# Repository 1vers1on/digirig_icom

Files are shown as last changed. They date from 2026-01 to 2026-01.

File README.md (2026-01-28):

# ICOM IC-2730 Digital Controller

A custom hardware controller for the ICOM IC-2730 radio, featuring digital audio processing and USB connectivity.

## Overview

This project provides a digital interface for the ICOM IC-2730 radio using a Raspberry Pi RP2350 microcontroller and TLV320AIC3204 audio codec. It handles both transmit and receive audio digitally while managing the radio's unique logic level requirements.

## Hardware
### Main Components

- **Microcontroller: Raspberry Pi RP2350**
  - High processing power
  - Native USB support
  - Familiar development ecosystem

- **Audio Codec: TLV320AIC3204**
  - Integrated DAC and ADC
  - High-quality audio processing

## Key Features
  - USB connectivity for computer interface
  - Bidirectional audio processing (TX/RX)
  - Analog switching circuitry
  - LDO power regulation
  - 3D-printed enclosure with screw mounting

## Design Challenges
**Logic Level Weirdness**
The ICOM IC-2730 uses some very unusual logic levels that I've never encountered before:

- High: 5V
- Low: 3.1V (yes, really!)

**Solution**

- RX path: LM393 comparator to handle the odd voltage levels
- TX path: 5V level shifter (if it reads 3.1V as low, it should read 0V as low too)

**Power Management**
Originally considered a buck converter for efficiency, but went with an LDO since it's perfectly adequate for this application and simpler to implement.

## Notes

- This was my first time using Fusion 360 for CAD work
- Spent way too long figuring out MOSFET power switching
- Enclosure uses screws instead of glue for user serviceability

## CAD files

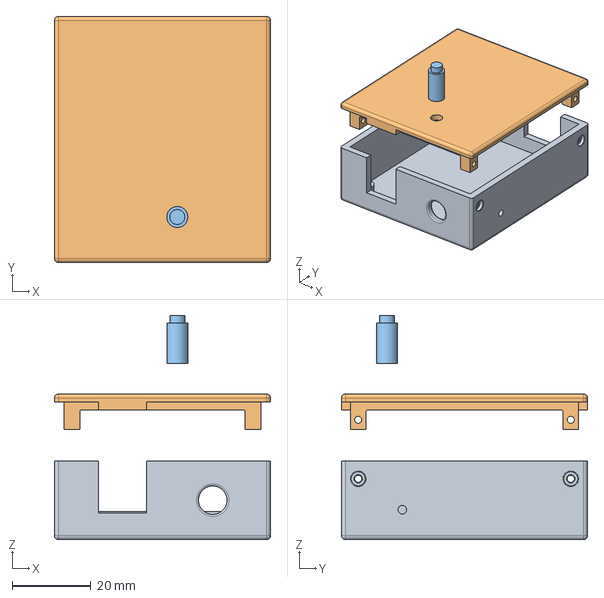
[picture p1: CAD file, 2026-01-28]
icom_digirig_case.step
54.9 x 62.5 x 57.0 mm

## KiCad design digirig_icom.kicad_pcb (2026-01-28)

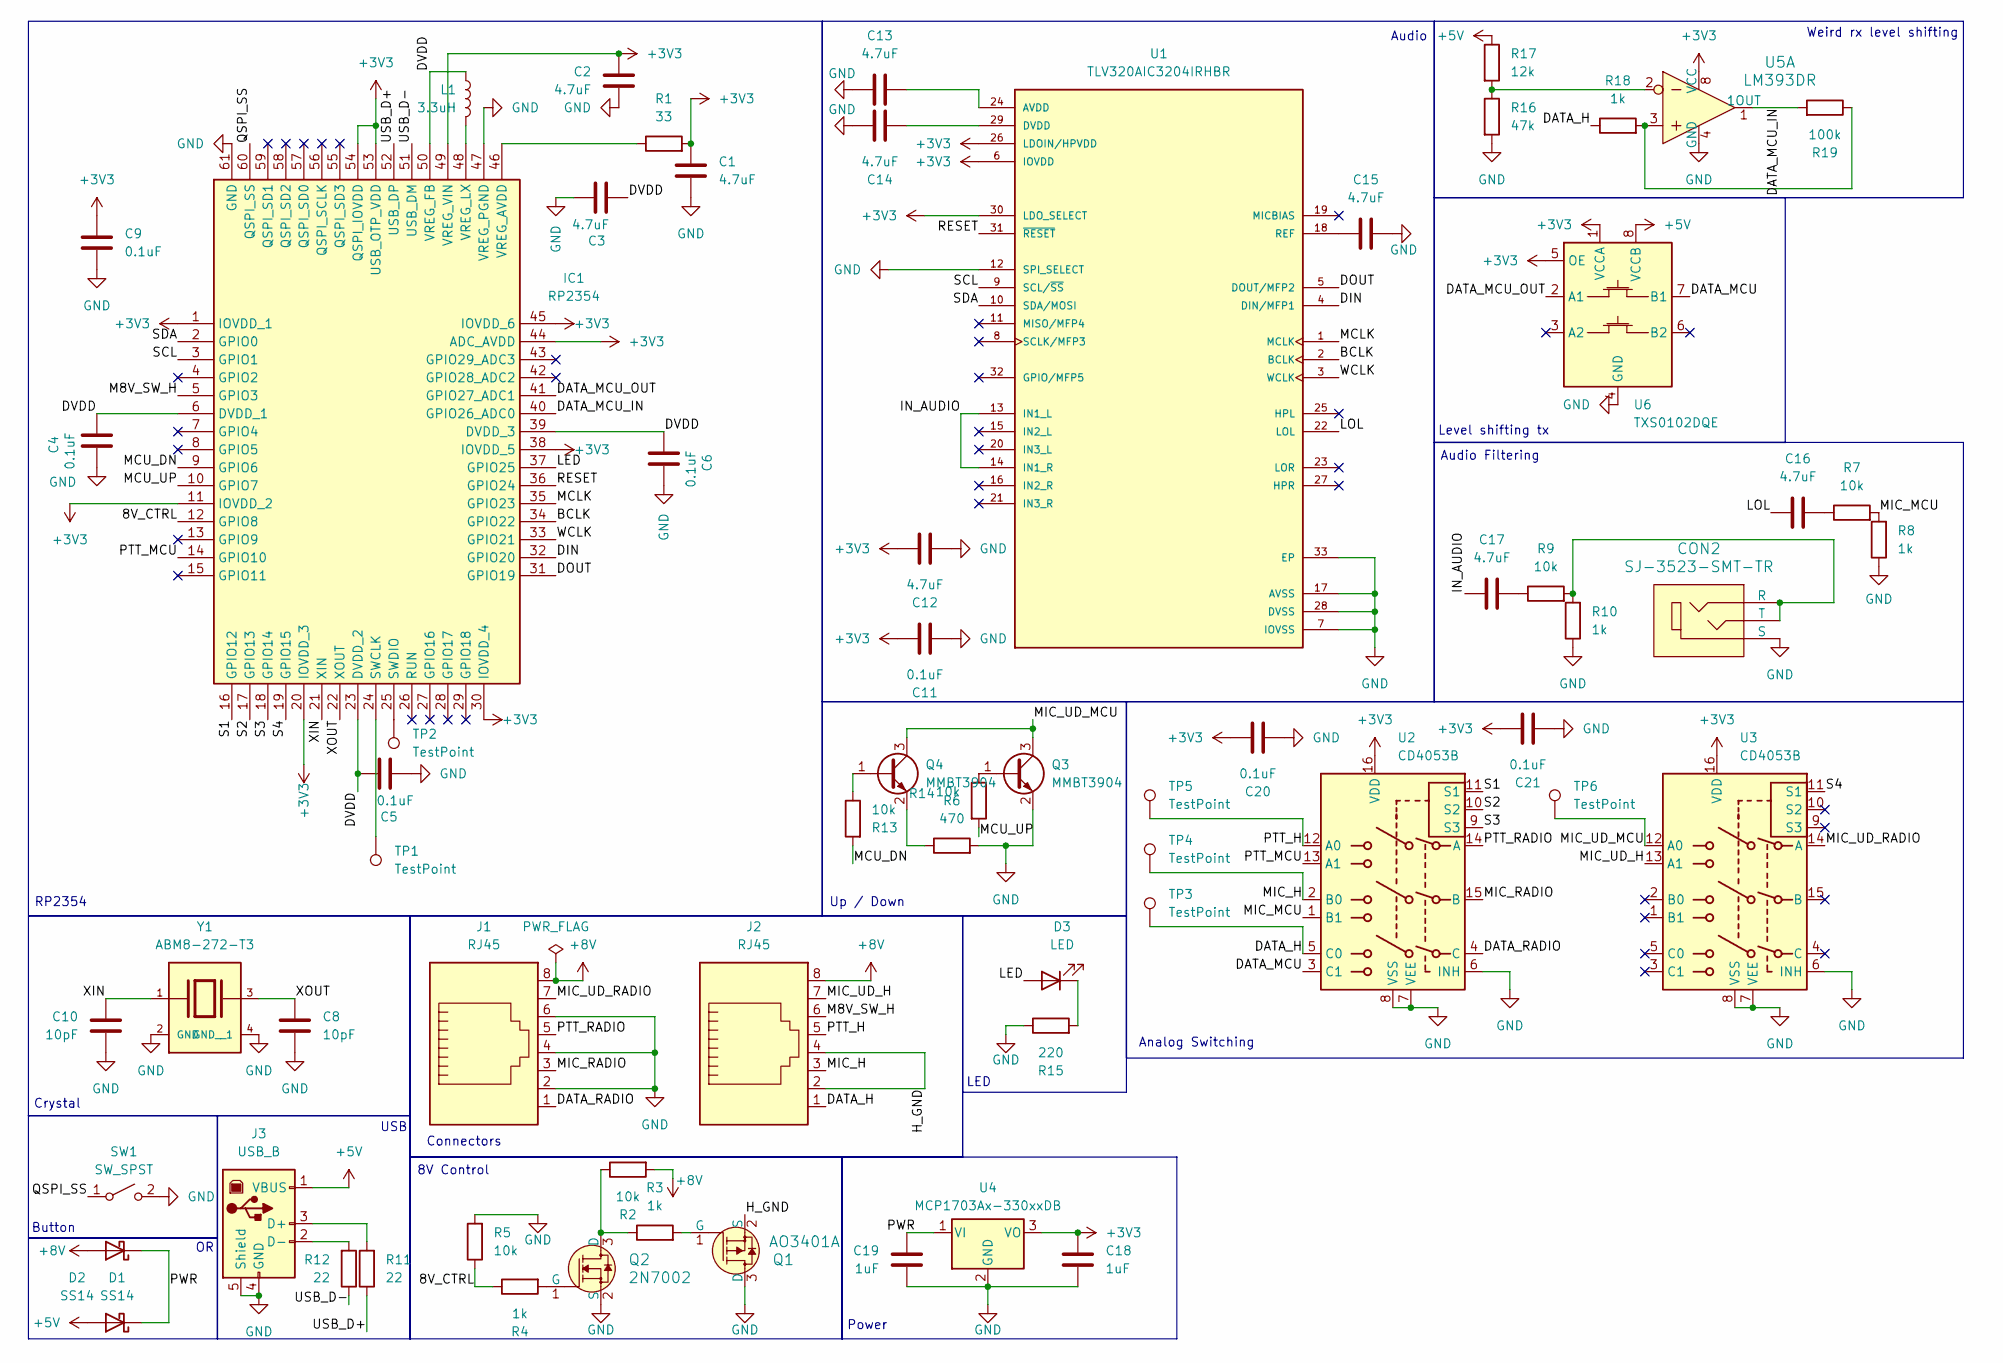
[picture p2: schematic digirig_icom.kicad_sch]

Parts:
C1, C2, C3, C12, C13, C14, C15, C16, C17: 4.7uF; C_0402_1005Metric; Digi-Key_PN 1276-1482-2-ND
C4, C5, C6, C9, C11, C20, C21: 0.1uF; C_0402_1005Metric; Digi-Key_PN 1276-1043-2-ND
C8, C10: 10pF; C_0402_1005Metric; Digi-Key_PN 490-6186-2-ND
C18, C19: 1uF; C_0402_1005Metric; Digi-Key_PN 1276-1010-2-ND
CON2: SJ-3523-SMT-TR; Switch_Slide_11.6x4mm_SJ-3523-SMT; MPN SJ-3523-SMT-TR; Digi-Key_PN CP-3523SJCT-ND
D1, D2: SS14; D_SMA; Digi-Key_PN SS14TR-ND
D3: LED; LED_0603_1608Metric; Digi-Key_PN 475-LSQ976-NR-1TR-ND
IC1: RP2354; QFN40P700X700X90-61N-D; Manufacturer_Part_Number RP2350A-CT; Digi-Key_PN 2648-SC1511(13)-A4TR-ND
J1, J2: RJ45; RJ45_Amphenol_54602-x08_Horizontal; Digi-Key_PN 609-1046-ND
J3: USB_B; USB_B_Lumberg_2411_02_Horizontal; Digi-Key_PN 5405-241106-ND
L1: 3.3uH; AOTAB201610S3R3101T; Digi-Key_PN 535-AOTA-B201610S3R3-101-TTR-ND
Q1: AO3401A; SOT-23-3; MPN AO3401A; Digi-Key_PN 785-1001-1-ND
Q2: 2N7002; SOT-23-3; MPN 2N7002; Digi-Key_PN 2N7002NCT-ND
Q3, Q4: MMBT3904; SOT-23; Digi-Key_PN 4878-MMBT3904TR-ND
R1: 33; R_0402_1005Metric; Digi-Key_PN 311-33JRTR-ND
R2, R5, R7, R9, R13, R14: 10k; R_0402_1005Metric; Digi-Key_PN 311-10.0KLRTR-ND
R3, R4, R8, R10, R18: 1k; R_0402_1005Metric; Digi-Key_PN 311-1.0KJRTR-ND
R6: 470; R_0402_1005Metric; Digi-Key_PN 311-470LRTR-ND
R11, R12: 22; R_0402_1005Metric; Digi-Key_PN 311-22.0LRTR-ND
R15: 220; R_0603_1608Metric; Digi-Key_PN 311-220HRTR-ND
R16: 47k; R_0402_1005Metric; Digi-Key_PN 311-47.0KLRTR-ND
R17: 12k; R_0402_1005Metric; Digi-Key_PN P12KDCTR-ND
R19: 100k; R_0402_1005Metric; Digi-Key_PN 311-100KJRTR-ND
SW1: SW_SPST; SW_SPST_CK_RS282G05A3; Digi-Key_PN CKN10384TR-ND
TP1, TP2, TP3, TP4, TP5, TP6: TestPoint; TestPoint_Pad_D1.0mm
U1: TLV320AIC3204IRHBR; QFN50P500X500X100-33N; PARTREV E; Digi-Key_PN 296-23775-2-ND
U2, U3: CD4053B; TSSOP-16_4.4x5mm_P0.65mm; Digi-Key_PN 296-14117-2-ND
U4: MCP1703Ax-330xxDB; SOT-223-3_TabPin2; Digi-Key_PN MCP1703A-3302E/DB-ND
U5: LM393DR; SOIC-8_W3.9mm; MPN LM393DR; Digi-Key_PN 296-1015-1-ND
U6: TXS0102DQE; X2SON-8_1.4x1mm_P0.35mm; Digi-Key_PN 296-28368-2-ND
Y1: ABM8-272-T3; XTAL_ABM8-272-T3; PARTREV 07-29-20; Digi-Key_PN 535-ABM8-272-T3TR-ND

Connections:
+3V3: C1.1, C2.2, C9.2, C11.1, C12.1, C18.1, C20.1, C21.1, IC1.1 (IOVDD_1), IC1.11 (IOVDD_2), IC1.20 (IOVDD_3), IC1.30 (IOVDD_4), IC1.38 (IOVDD_5), IC1.44 (ADC_AVDD), IC1.45 (IOVDD_6), IC1.49 (VREG_VIN), IC1.53 (USB_OTP_VDD), IC1.54 (QSPI_IOVDD), R1.2, U1.6 (IOVDD), U1.26 (LDOIN/HPVDD), U1.30 (LDO_SELECT), U2.16 (VDD), U3.16 (VDD), U4.3 (VO), U5.8 (VCC), U6.1 (VCCA), U6.5 (OE)
+5V: D1.2 (A), J3.1 (VBUS), R17.1, U6.8 (VCCB)
+8V: D2.2 (A), J1.8, J2.8, R2.2
/8V_CTRL: IC1.12 (GPIO8), R4.1, R5.1
/BCLK: IC1.34 (GPIO22), U1.2 (BCLK)
/DATA_H: J2.1, R18.1, TP3.1, U2.5 (C0)
/DATA_MCU: U2.3 (C1), U6.7 (B1)
/DATA_MCU_IN: IC1.40 (GPIO26_ADC0), R19.2, U5.1 (1OUT)
/DATA_MCU_OUT: IC1.41 (GPIO27_ADC1), U6.2 (A1)
/DATA_RADIO: J1.1, U2.4 (C)
/DIN: IC1.32 (GPIO20), U1.4 (DIN/MFP1)
/DOUT: IC1.31 (GPIO19), U1.5 (DOUT/MFP2)
/DVDD: C3.1, C4.1, C5.1, C6.1, IC1.6 (DVDD_1), IC1.23 (DVDD_2), IC1.39 (DVDD_3), IC1.50 (VREG_FB), L1.2
/H_GND: J2.2, J2.4, Q1.2 (S)
/IN_AUDIO: C17.1, U1.13 (IN1_L), U1.14 (IN1_R)
/LED: D3.2 (A), IC1.37 (GPIO25)
/LOL: C16.1, U1.22 (LOL)
/M8V_SW_H: IC1.5 (GPIO3), J2.6
/MCLK: IC1.35 (GPIO23), U1.1 (MCLK)
/MCU_DN: IC1.9 (GPIO6), R13.2
/MCU_UP: IC1.10 (GPIO7), R14.2
/MIC_H: J2.3, TP4.1, U2.2 (B0)
/MIC_MCU: R7.2, R8.2, U2.1 (B1)
/MIC_RADIO: J1.3, U2.15 (B)
/MIC_UD_H: J2.7, U3.13 (A1)
/MIC_UD_MCU: Q3.3 (C), Q4.3 (C), TP6.1, U3.12 (A0)
/MIC_UD_RADIO: J1.7, U3.14 (A)
/PTT_H: J2.5, TP5.1, U2.12 (A0)
/PTT_MCU: IC1.14 (GPIO10), U2.13 (A1)
/PTT_RADIO: J1.5, U2.14 (A)
/PWR: C19.1, D1.1 (K), D2.1 (K), U4.1 (VI)
/QSPI_SS: IC1.60 (QSPI_SS), SW1.1 (A)
/RESET: IC1.36 (GPIO24), U1.31 (~RESET)
/S1: IC1.16 (GPIO12), U2.11 (S1)
/S2: IC1.17 (GPIO13), U2.10 (S2)
/S3: IC1.18 (GPIO14), U2.9 (S3)
/S4: IC1.19 (GPIO15), U3.11 (S1)
/SCL: IC1.3 (GPIO1), U1.9 (SCL/~SS)
/SDA: IC1.2 (GPIO0), U1.10 (SDA/MOSI)
/USB_D+: IC1.52 (USB_DP), R11.1
/USB_D-: IC1.51 (USB_DM), R12.1
/WCLK: IC1.33 (GPIO21), U1.3 (WCLK)
/XIN: C10.1, IC1.21 (XIN), Y1.1
/XOUT: C8.1, IC1.22 (XOUT), Y1.3
GND: C1.2, C2.1, C3.2, C4.2, C5.2, C6.2, C8.2, C9.1, C10.2, C11.2, C12.2, C13.2, C14.1, C15.1, C18.2, C19.2, C20.2, C21.2, CON2.1 (S), IC1.47 (VREG_PGND), IC1.61 (GND), J1.2, J1.4, J1.6, J3.4 (GND), J3.5 (Shield), Q1.3 (D), Q2.2 (S), Q3.2 (E), R5.2, R6.2, R8.1, R10.1, R15.1, R16.2, SW1.2 (B), U1.7 (IOVSS), U1.12 (SPI_SELECT), U1.17 (AVSS), U1.28 (DVSS), U1.33 (EP), U2.6 (INH), U2.7 (VEE), U2.8 (VSS), U3.6 (INH), U3.7 (VEE), U3.8 (VSS), U4.2 (GND), U5.4 (GND), U6.4 (GND), Y1.2 (GND), Y1.4 (GND__1)
unnamed: C16.2, R7.1
unnamed: C17.2, R9.1
unnamed: CON2.2 (T), CON2.3 (R), R9.2, R10.2
unnamed: D3.1 (K), R15.2
unnamed: IC1.24 (SWCLK), TP1.1
unnamed: IC1.25 (SWDIO), TP2.1
unnamed: IC1.46 (VREG_AVDD), R1.1
unnamed: IC1.48 (VREG_LX), L1.1
unnamed: J3.3 (D+), R11.2
unnamed: J3.2 (D-), R12.2
unnamed: Q1.1 (G), R3.2
unnamed: Q2.3 (D), R2.1, R3.1
unnamed: Q2.1 (G), R4.2
unnamed: Q3.1 (B), R14.1
unnamed: Q4.1 (B), R13.1
unnamed: Q4.2 (E), R6.1
unnamed: R16.1, R17.2, U5.2
unnamed: R18.2, R19.1, U5.3
unnamed: C13.1, U1.24 (AVDD)
unnamed: C14.2, U1.29 (DVDD)
unnamed: C15.2, U1.18 (REF)

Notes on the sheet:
Audio Filtering
Up / Down
RP2354
Weird rx level shifting
LED
8V Control
Level shifting tx
Analog Switching
Connectors
Audio
Crystal
Button
Power
USB

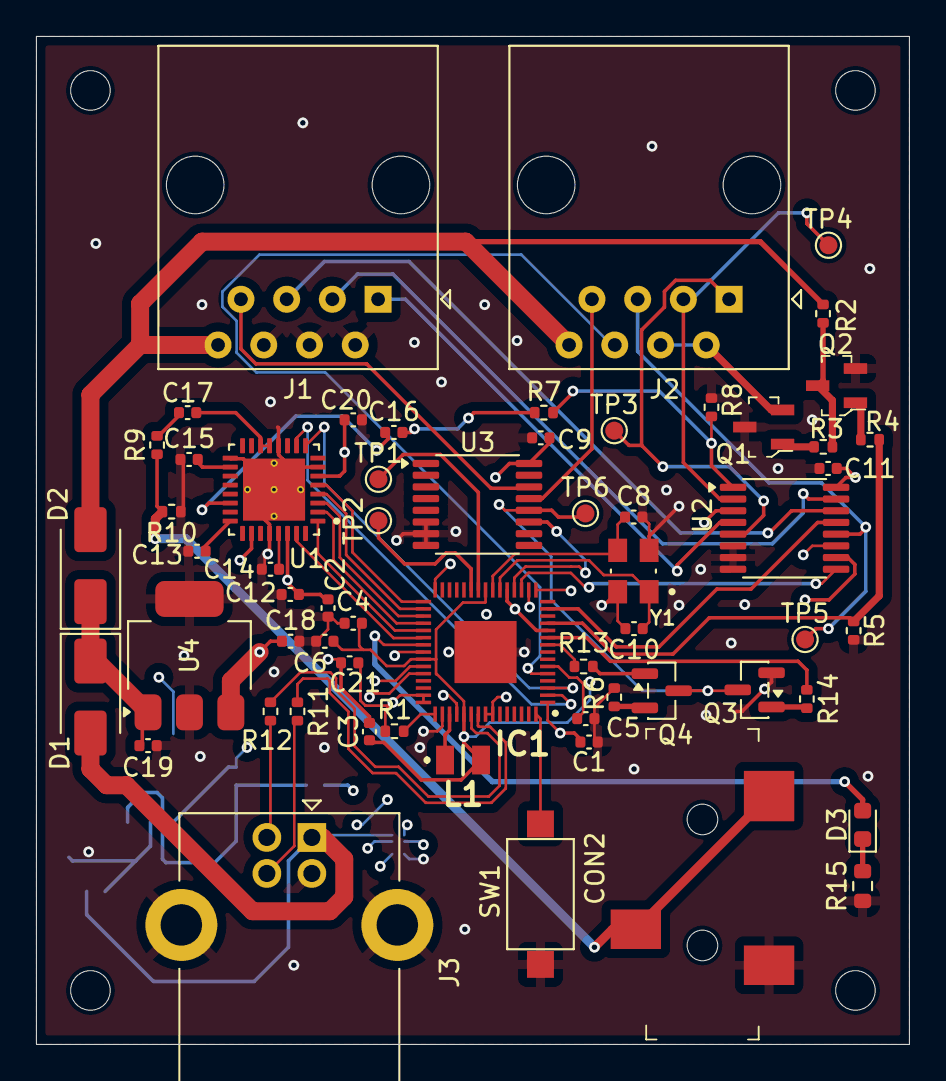
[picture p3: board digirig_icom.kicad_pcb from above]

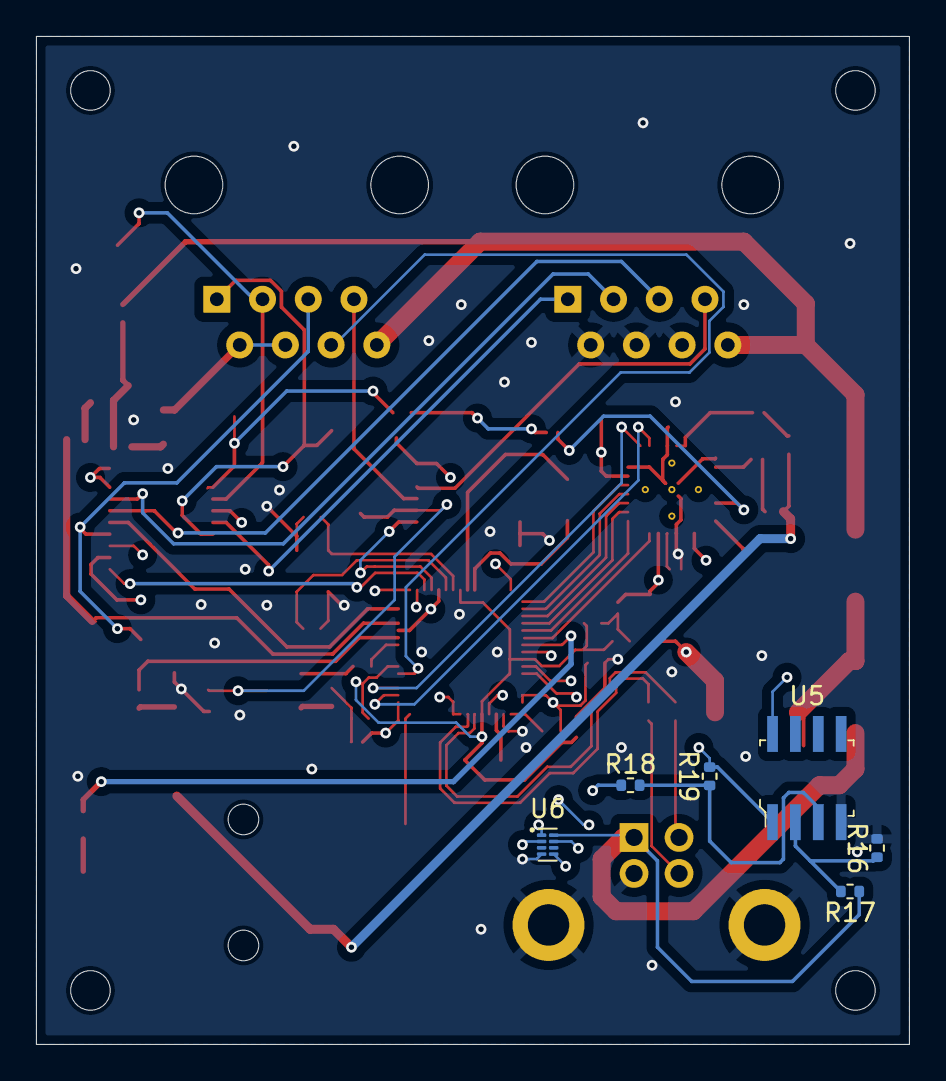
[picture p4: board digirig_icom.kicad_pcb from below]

Board: 4 copper layers, 48.5 x 56.0 mm, 66 parts (6 on the bottom side), 66 nets.

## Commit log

2026-01-28 Weird level shifting stuff I think
    [digirig_icom.kicad_pcb, digirig_icom.kicad_sch]
2026-01-28 remove gerbers
    [digirig_icom-B_Cu.gbr, digirig_icom-B_Mask.gbr, digirig_icom-B_Paste.gbr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]
2026-01-28 remove models
    [digirig_icom.step]
2026-01-28 Add 3d models for the case
    [icom_digirig_case.step]
2026-01-28 Fix some stuff
    [digirig_icom.kicad_pcb, digirig_icom.kicad_sch]
